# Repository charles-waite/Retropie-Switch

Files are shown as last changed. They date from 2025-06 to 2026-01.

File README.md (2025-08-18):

# Raspberry Switch

A handheld, modular, Raspberry Pi-based game console inspired by the Nintendo Switch.  
Designed for RetroPie gaming, open-source hacking, and custom hardware add-ons—housed in a 3D-printed case with real Switch Joycons and tailored for hardware tinkerers.

---

## Table of Contents

- [Project Overview](#project-overview)
- [Features](#features)
- [Hardware List](#hardware-list)
- [Case & Design Notes](#case--design-notes)
- [Joycon Rail Connector](#joycon-rail-connector)
- [To-Do](#to-do)
- [Setup & Install Instructions](#setup--install-instructions)
- [Development Roadmap](#development-roadmap)
- [License](#license)
- [Acknowledgments](#acknowledgments)

---

## Project Overview

**Raspberry Switch** is a DIY handheld gaming console based on the Raspberry Pi 3A+, with a 7" touchscreen, true Joycon compatibility, built-in audio, battery power, and an open 3D-printed enclosure.  
This project aims to be a “Switch-like” device running RetroPie, with modular Python scripts handling hardware functions like backlight, volume, overlay, battery status, and LED indicators.

All hardware and software designs are eventually intended to be open-sourced for others to build, adapt, and contribute.

---

## Features

- RetroPie-based, runs classic games on a handheld Pi
- 3D-printed clamshell case with access panels
- Real Nintendo Switch Joycon rails for detachable controls
- USB-C charging with PiSugar UPS and battery support
- 7” touchscreen display with adjustable backlight (including auto-brightness)
- Custom volume controls (including hardware mute and OSD overlay)
- Stereo amp and speakers (with mini DAC for high-quality audio)
- Headphone jack with auto-mute detection
- On-screen overlays for status and actions
- Status LEDs for power, charging, and battery
- Expandable via internal USB hub for extra controllers/devices
- Open design—schematics, scripts, and CAD files included

---

## Hardware List

- Raspberry Pi 3A+
- PiSugar 3 Plus (battery/UPS)
- 7” Touchscreen display
- Switch Joycon rails (or donor Joycon charger for rails/connector)
- Joycons
- Tiny stereo speakers
- Mini DAC (generic PCM5102A variant)
- Small hardware buttons (power, volume, etc.)
- USB-C charging input relocated/extended from PiSugar
- Liquid flux

---

## Progress pictures

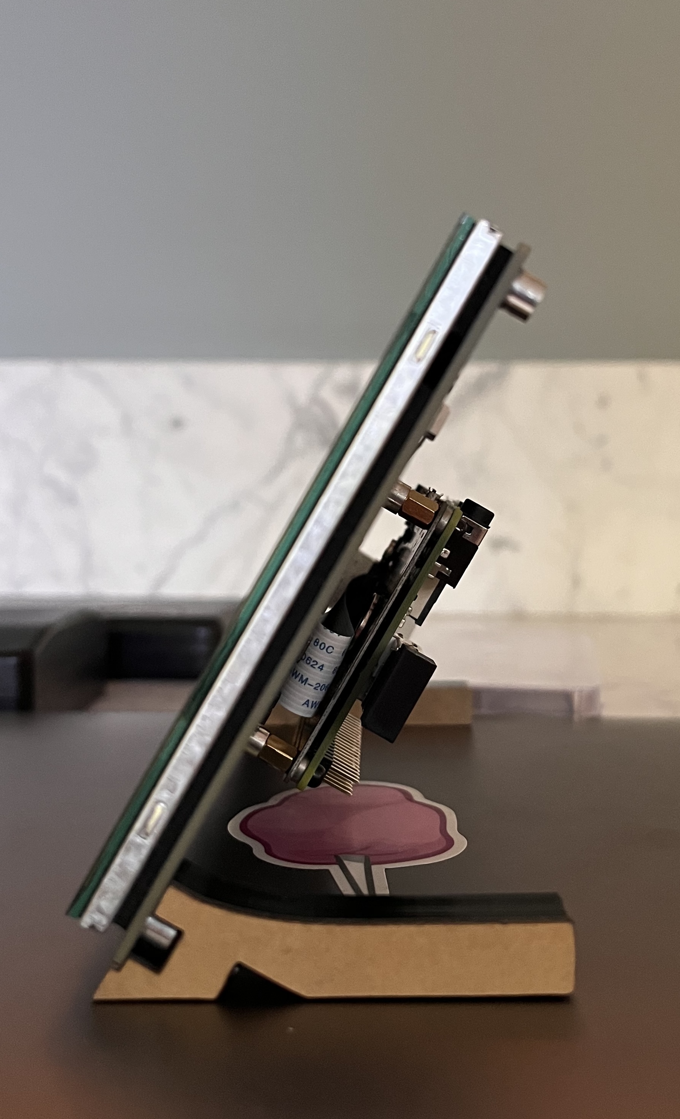
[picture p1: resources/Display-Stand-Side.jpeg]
Display Stand Side

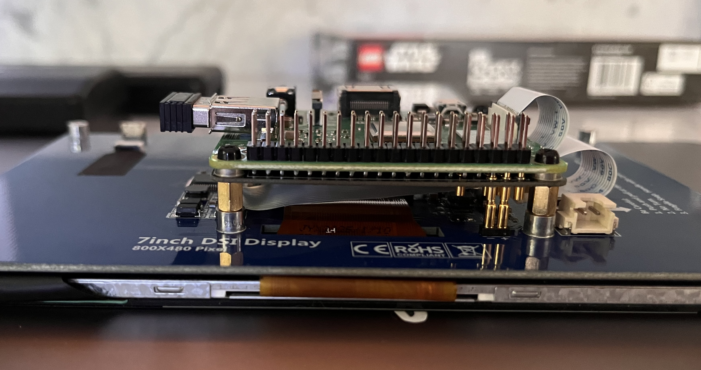
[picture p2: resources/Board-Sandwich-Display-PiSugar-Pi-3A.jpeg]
Board Sandwich


---

## Case & Design Notes

- Custom 3D-printed, clamshell design in two layers (screen bezel, rear case)
- Mounts for all internal components (speakers, amp, DAC, buttons, USB, Joycon rails)
- Foam or adhesive for clean fit to screen
- Mounts directly to LCD panel studs for a robust build

---

## To-Do

- [ ] **Design v1 case** (simple POC, clamshell, access ports)
    - Mounts for speakers, amp, headphone jack, DAC, buttons, USB, Joycon rails, controller board, battery
- [ ] **Integrate buttons** for volume, power, etc.
- [ ] **Upgrade to PiSugar 3 Plus** for power management
- [ ] **Add internal USB hub** (minimum 3 ports: 2 external, 1 internal for Joycons)
- [ ] **Optimize DAC mounting** for durability and space
- [ ] **Setup & test volume/mute buttons**, with auto-mute on headphone insertion
- [ ] **Setup backlight control script**, test with Joycons
- [x] **Create GitHub repo**
- [ ] **Create installer/setup script**
    - [ ] Registers system services at boot
    - [ ] Links scripts and services correctly
    - [ ] Includes update script for pulling changes & restarting services
- [ ] **Refactor scripts** to use Adafruit libraries for reliability
- [ ] **Determine ribbon cable orientation for Joycon rails**
- [x] **Design Joycon Rail cable extender and breakout board variants**
- [ ] **Design custom slider rails using a 4-pin connector to carry VIN/GND + I2C signal**
	- 	Could use a Magnetic "MagSafe" style plug, USB-C plugs, or something like a card edge connector.

---

## Setup & Install Instructions

### 1. Prepare SD Card

- Download and flash the RetroPie IMG to your SD card, or
- Install Raspbian 64-bit Lite (Bookworm) to SD

> **Note for Pi 3/3+:**  
> - Disable WiFi Power Management:  
>   Edit `/etc/rc.local` and add:  
>   ```sh
>   /sbin/iwconfig wlan0 power off
>   exit 0
>   ```
>   Run: `sudo chmod 755 /etc/rc.local`
> - Follow [raspberrypi5-retropie-setup instructions](https://github.com/danielfreer/raspberrypi5-retropie-setup)

### 2. Boot Configuration

- Edit `boot.txt`, comment out `#dtparam=audio=on`
- (Double-check these steps for Bookworm compatibility)

### 3. System Updates

- `sudo apt-get update`
- `sudo apt-get upgrade`
- Boot into RetroPie, run system updates

### 4. Audio & Volume Controls

- Configure virtual sound card for SoftVolume control
- Set up hardware volume/mute buttons and OSD overlay
- Integrate auto-mute on headphone detection (using headphone jack GPIO switch)

### 5. Backlight & Sensor

- Connect and script ambient light sensor to GPIO for auto backlight
- Connect LCD backlight control to GPIO/PWM pin

### 6. Joycon Rails

- Wire rails using Molex ribbon cables per plan above
- Test fit for correct cable orientation and slot routing

### 7. Installer Script (planned)

- Run installer script to set up services and scripts at boot
- Update script for future improvements

---

## Development Roadmap

- Modular Python scripts for backlight, volume, overlay, battery, and status LEDs
- Hardware abstraction to allow swapping components (DAC, screen, battery, etc.)
- Easy-to-follow setup and assembly documentation (including CAD files and images)
- Comprehensive OSD overlay for quick status/config access
- Plug-and-play Joycon integration
- Planned public open-source release when project reaches v1.0

---

## License

*To be added upon public release. Consider using [MIT](https://choosealicense.com/licenses/mit/) or [GPLv3](https://choosealicense.com/licenses/gpl-3.0/) license.*

---

## Acknowledgments

- Inspired by the Nintendo Switch, RetroPie, and countless open-source handheld projects

---

## Contributing

*Contributions, feedback, and hardware test reports are welcome! Please open issues or pull requests once the repo is public.*

---

## Contact

Project lead: charles-waite  
For questions, suggestions, or to get involved, open an issue.

---

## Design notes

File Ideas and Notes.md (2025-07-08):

**Raspberry Switch**

**Ideas:**

**A RetroPie-based Switch clone**

3D Printed Case (custom or using existing design as template)

- Built-in RPi 3A + Battery/UPS + Stereo Amp + Speakers
- Switch Joycon rails wired to charge joycons
- Removable back panel for access to Pi
- Mounts to lcd panel studs
- Gasket/adhesive for clean fit to screen

Ergo-Grips for real Joycons

- Or 3rd Party Ergo Joycon replacements with switch rails
- May need a premade joycon charger to pillage parts from

RetroPie

7” Touchscreen

Relocated Headphone Jack

USB-C charging jack on top or side wired to battery/UPS

Power Button

Volume buttons (or figure out OSD solution)

v2 - External HDMI port (hdmi over usbc?)

**Parts List:**

Pi 3 A+

PiSugar 3 Plus

7” Touchscreen

Switch Side rails -OR- Joycon charger to pillage 

Joycons

Tiny Stereo Speakers

Small buttons for power/volume

USB-C connector

Small gauge wires

Liquid flux

Small gauge solder

**Plan for joycon:**

- Scavenge board and rails from charging joycon
- Solder tiny wires to rail ribbon cable to extend connection to board from far sides
- Should work with *Joycond* out of the box via USB
- Connect to USB bus with wires rather than connector

**Plan for audio**

- BT audio is a non-starter for now
- Use mini DAC 
- Setup SoftVol to control volume to DAC
- Wire speaker amp to rca output pads on DAC
- Use I2C gain controls on amp to turn it all the way down when both volume buttons are pressed (this will functionally work as a mute switch too)
  - Need to figure out button combos and long press for this to work properly.
- Pressing both buttons again restores the gain value back to a specified setting.
- Maybe switch volume controls to be more logarithmic?

**Design a popup menu for custom actions to be run**

- Could be used to manually mute audio or run scripts to make basic config changes.

**Ambient light sensor for backlight**

Automate backlight brightness using a photocell.

- Can use a cheap phototransistor tied to gpio.
- LCD Backlight can be connected to GPIO-PWM pin and controlled with code
- Could find a script that will monitor that pin and change the output accordingly.

**Space for Audio stuff**

- Mount to lid
- DAC uses gpio header
- Amp is wired to DAC and gets power from GPIO

**USB**

Do I even need more than one? 

- Loading roms over USB
- Secondary controllers? 
- Internal hub (adafruit breakout board) with an externally accessible port or two?

**Status LEDs**

(Tested with adafruit 5mm LEDs https://www.adafruit.com/product/4203)

Green = 220 Ω

Blue = 4,700 Ω

Red = 2,200 Ω

This may differ when I try 3mm ones. Or I could do RGB using a software PWM and a 4-pin RGB LED.

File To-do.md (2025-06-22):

To-do:

- [ ] Design v1 Case

  	Just a POC, can be blocky and doesn't need mounting points for hardware, just space for things to fit. I can use this to mark out where components can mount 

  	Clamshell design in 2 layers: screen bezel, rear case, access port for Pi

  	Mounts include: 

  		• Speakers

  		• Amp board

  		• Headphone Jack (should get a mountable version, breadboard one isnt ideal)

  		• DAC (needs to be really secure to handle GPIO insertion and removal)

  		• Buttons w/ rocker switch pieces

  		• USB ports

  		• Joycon Rails

  		• Joycon controller board

  		• Battery	

- [ ] Integrate buttons for volume, power, etc

- [ ] Upgrade to PiSugar 3Plus to get power on/off

- [ ] Integrate a USB hub: 2 data ports external, one internal for Joycons.

  	• Maybe find a USB hub at home and scavenge it?

  	• Minimum 3 ports

- [ ] Install a header shim to double the 2x20 ports for more seamless connection for buttons, audio amp, usb, etc

- [ ] Consider a [short female header](https://www.adafruit.com/product/2243) for the DAC to save space (may not work with the gpio shim, maybe stack them and solder together?)

- [ ] Setup and test Volume mute button code w/ auto-mute on headphone insertion.

  	• Wire up headphone switch to GPIO to trigger automatic mute (Inner pins are open when headphones are inserted, DAC supports this)

- [ ] Setup Backlight control script and test with Joycons.

- [x] Create Github Repo

- [ ] Create installer/setup script

  - [ ] Creates and registers system services and runs them at boot
  - [ ] Links services to correct locations (would be /home/pi/*REPO-NAME*)
  - [ ] installs scripts to correct directories
  - [ ] Create update script that pulls new scripts and restarts systemctl and services

- [ ] Refactor script to use Adafruit python libraries (since ChatGPT keeps fucking up the registers and forgetting functionality)

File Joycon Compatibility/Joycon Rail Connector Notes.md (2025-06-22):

## Tech Specs

#### Rail-side connector:

Pitch: .5mm

Compatible connector: [Molex 5034801000](https://www.digikey.com/en/products/detail/molex/5034801000/2356624)

Compatible cable: Molex [15020 (top-side pads)](https://www.digikey.com/en/products/filter/flat-flex-ribbon-jumpers-cables/457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) or [Molex 15120(opposite side pads)](https://www.digikey.com/en/products/filter/flat-flex-ribbon-jumpers-cables/457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) (length and pad side determined by routing layout and connectors)

#### Mounting plan:

1. Desolder original rail connector from original cable.
2. Solder original rail connector to one side of Molex flat cable.
3. Solder new molex connector to original cable.
4. Run flat cable through case to reach joycon board location.
5. New molex flat cable will plug into new connector on original cable

#### To-Do

Need to determine if same-side or opposite-side cables are needed for each side by doing a test fit with paper.

A slot will need to be designed into the rail mounting surface of the case in order to accomodate the new ribbon cable.

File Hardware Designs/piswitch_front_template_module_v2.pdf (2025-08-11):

| Active 154.89 x 87.50 mm (offset 1.62 L, 2.38 U)
| Module outline 164.89 x 100.00 mm
Left grip, 15.0° outward | | Right grip, 15.0° outward

Rail zone

Rail zone

Bezel mm: L=3.25 R=6.5 T=3.75 B=8.5; Active offset = 1.62 L, 2.38 U Print at 100% for 1:1.

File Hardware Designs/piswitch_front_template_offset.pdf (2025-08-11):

| Screen plate 176.4 x 115.4 mm (+12 mm uniform bezel) | Active area 152.4 x 91.4 mm (offset 1.62 mm L, 2.38 mm U)
Left grip, 15.0° outward | | | Right grip, 15.0° outward

Rail zone

Rail zone

Page: 300 x 160 mm. Print at 100% for 1:1.
Offset from bezel widths (mm): L=3.25 R=6.5 T=3.75 B=8.5

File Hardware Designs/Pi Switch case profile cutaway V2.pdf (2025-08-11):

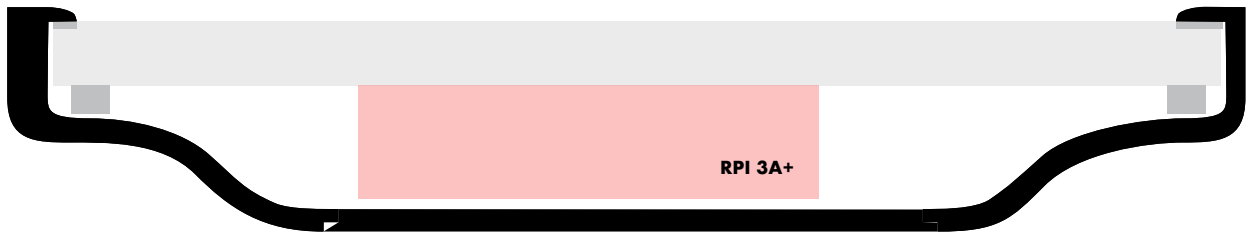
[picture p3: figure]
RPI 3A+

SHORT SIDE CROSS-SECTION

LONG SIDE CROSS-SECTION (FROM BOTTOM)

BEZEL WIDTHS

TOP: | 3.75MM
BOTTOM: | 8.50MM
LEFT: | 3.25MM
RIGHT: | 6.50MM

RPI 3A+

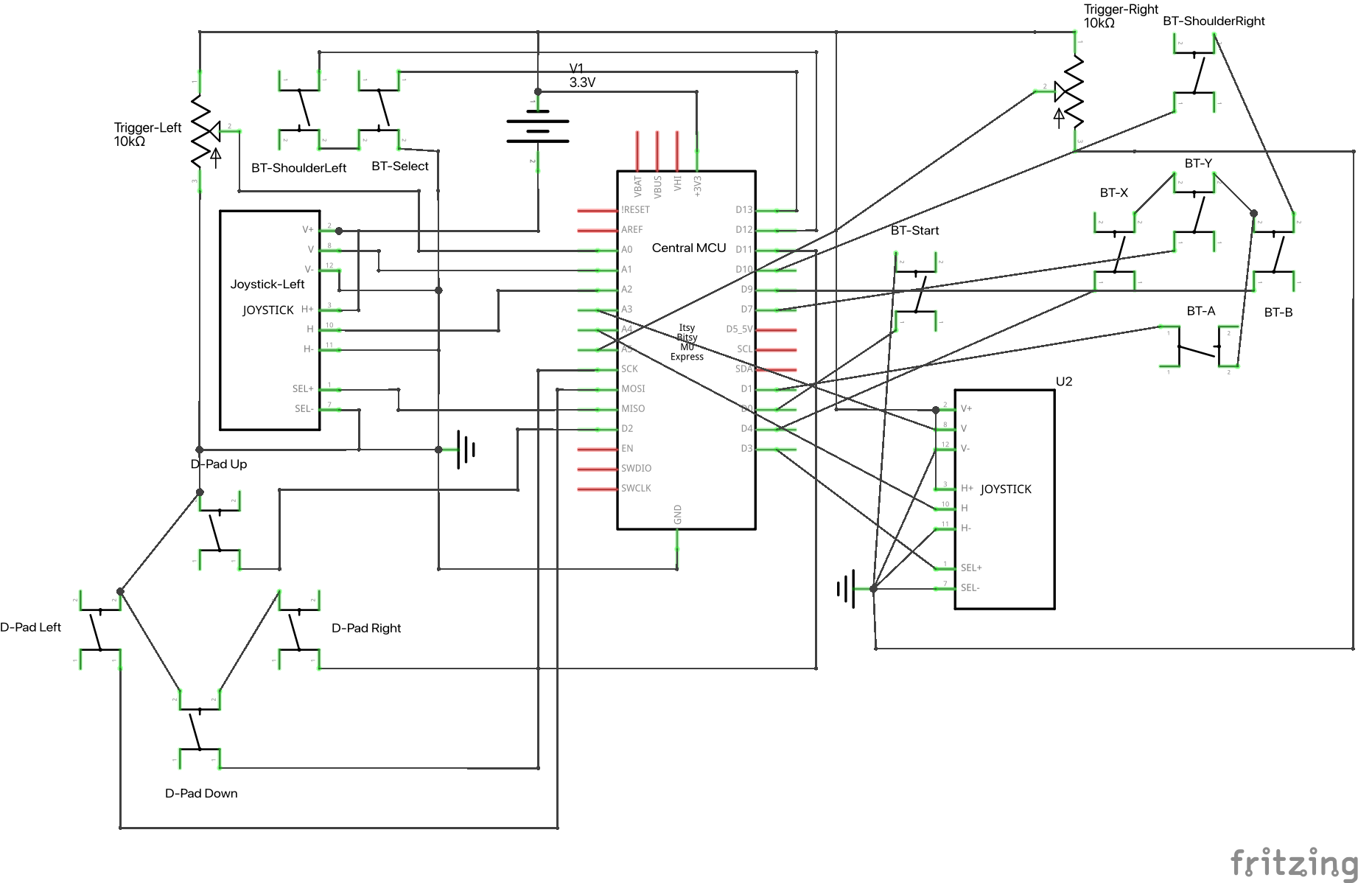
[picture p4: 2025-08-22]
Hardware Designs/Unified controller_schem.png

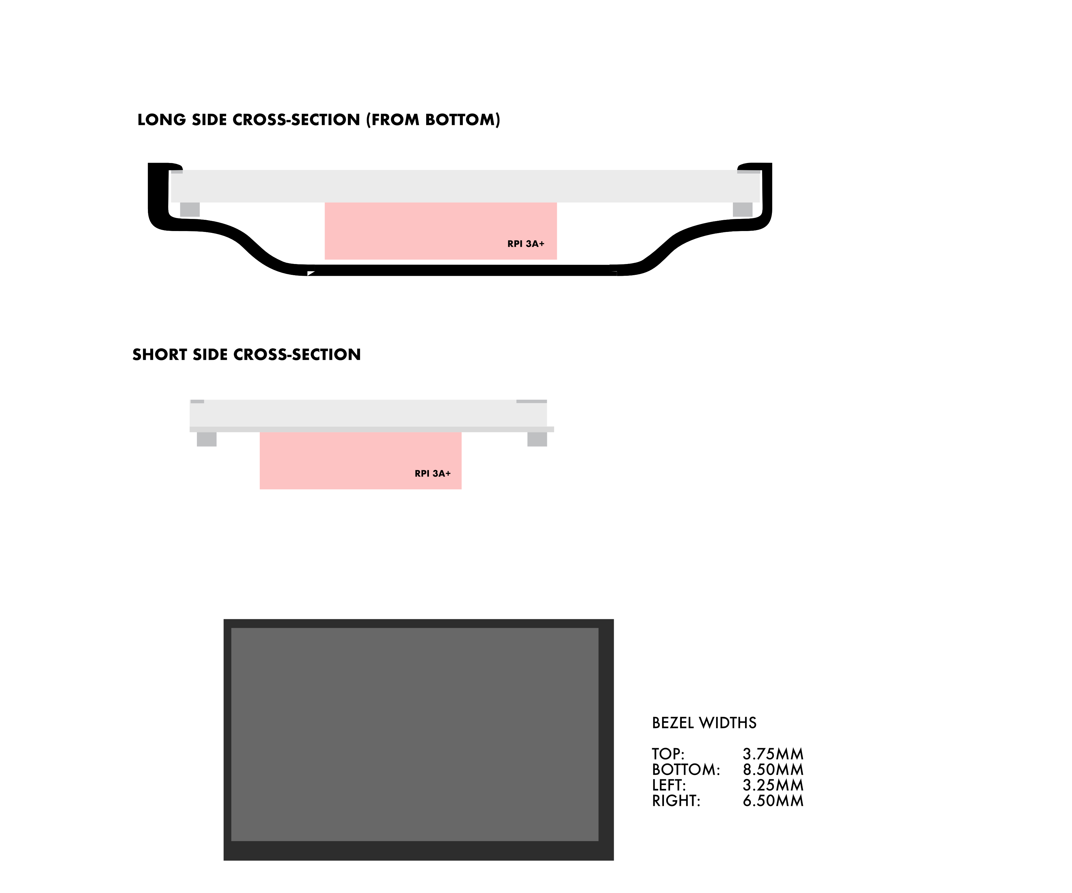
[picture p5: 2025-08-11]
Hardware Designs/Pi Switch case profile cutaway v2.png

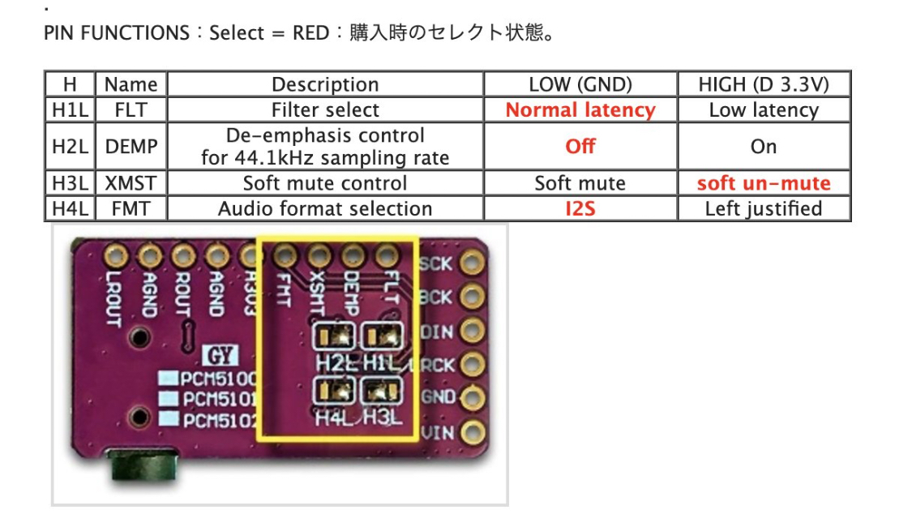
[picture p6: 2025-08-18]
resources/PCM5102A-board-jumper-pinout.jpeg

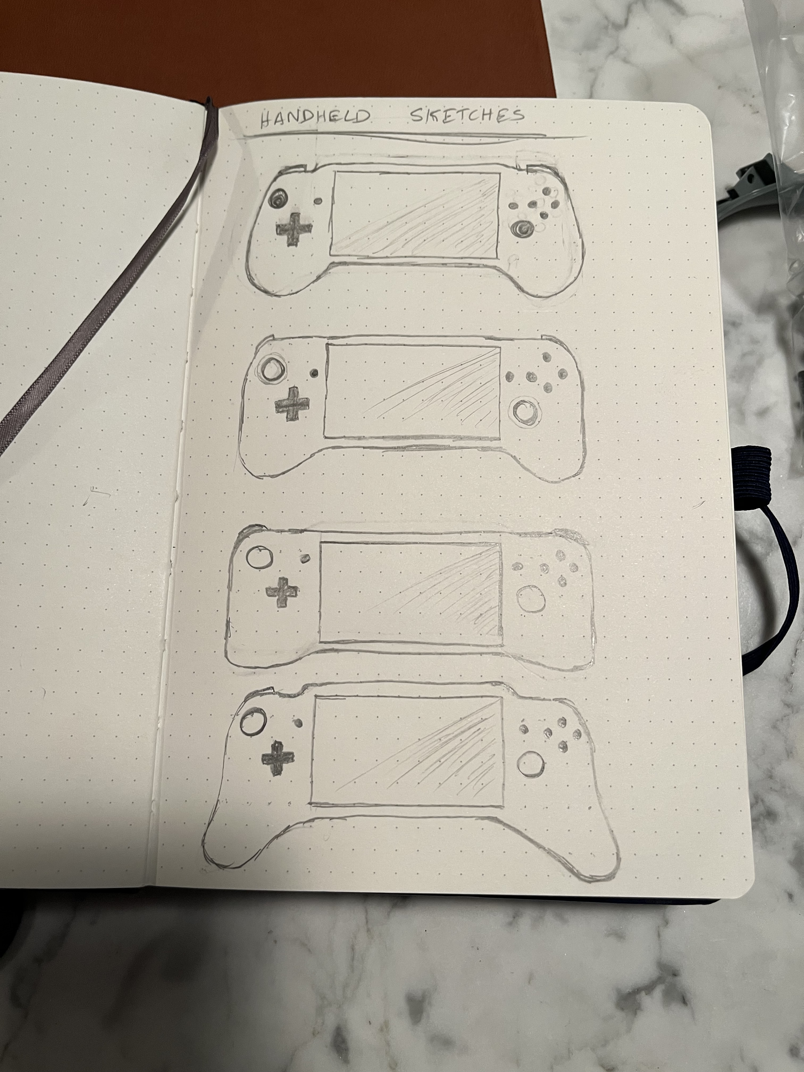
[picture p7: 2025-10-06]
resources/PiSwitch case Sketches.jpeg

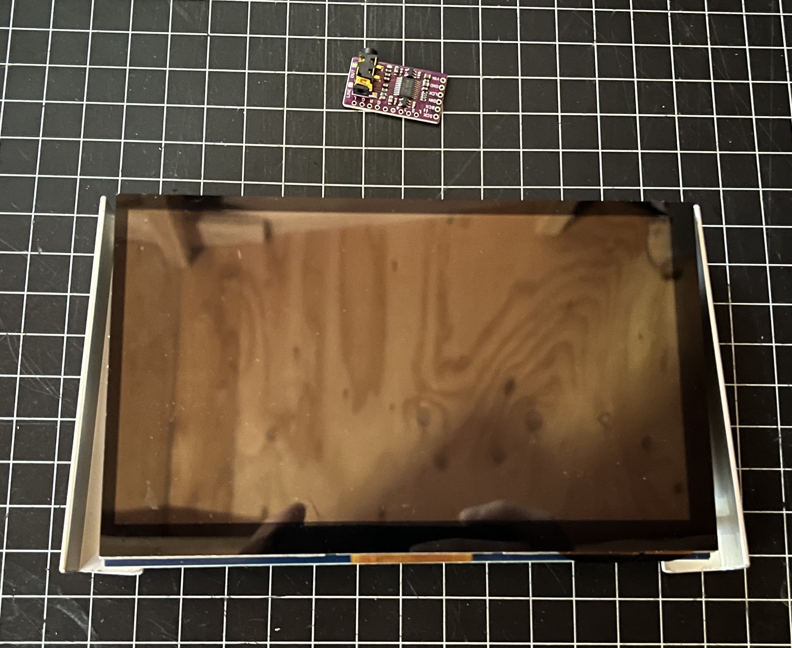
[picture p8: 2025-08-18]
resources/Prototype-Front-view.jpeg

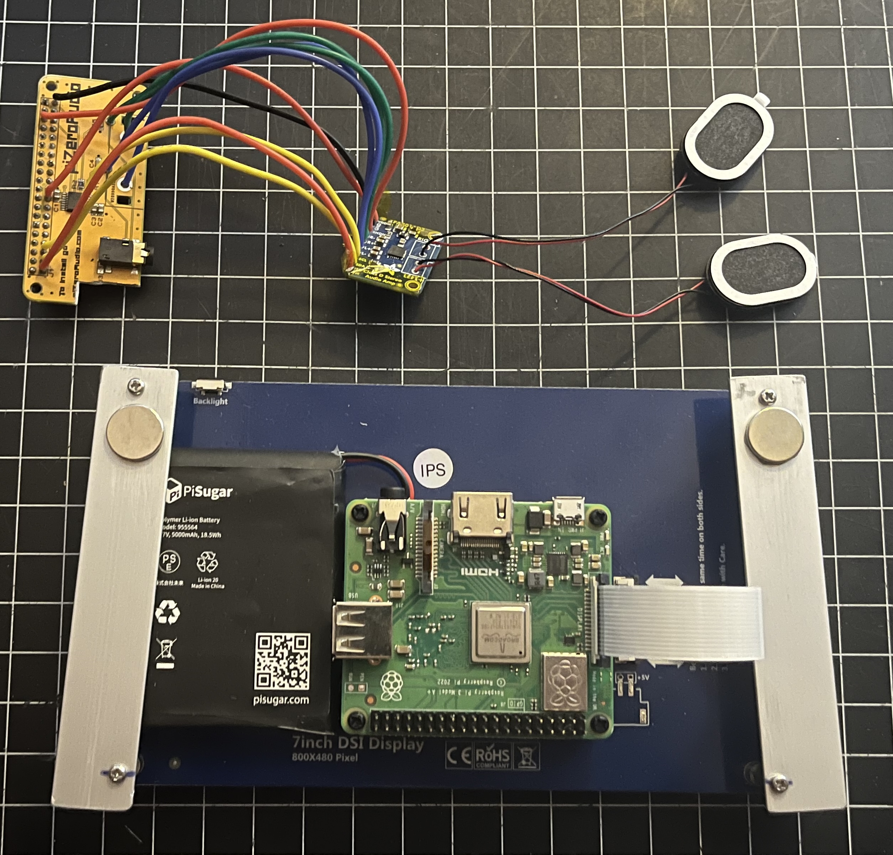
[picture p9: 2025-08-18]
resources/Prototype-Back-view.jpeg

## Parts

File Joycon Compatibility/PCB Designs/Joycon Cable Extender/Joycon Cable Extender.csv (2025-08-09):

Reference | Qty | Value | DNP | Exclude from BOM | Exclude from Board | Footprint | Datasheet
J3,J4 | 2 | Molex_5035661102 |  |  |  | CON_5035661102_MOL | https://www.molex.com/en-us/products/part-detail-pdf/5035661102?display=pdf

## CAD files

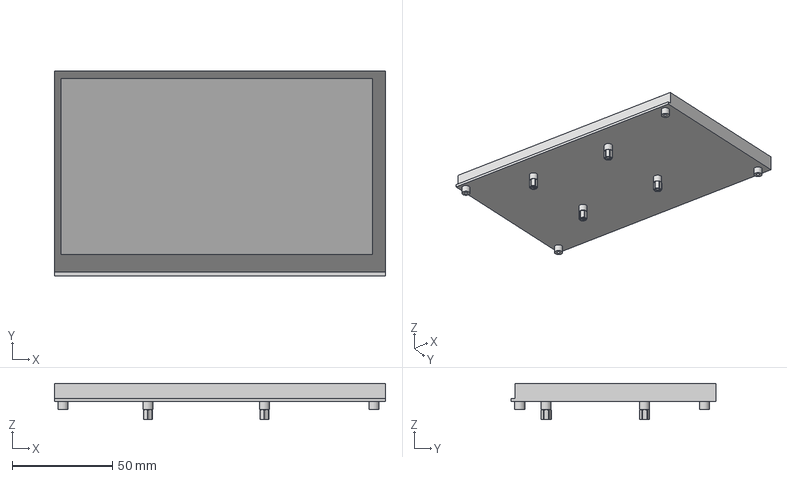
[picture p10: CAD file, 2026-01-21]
Hardware Designs/Models/7-inch Screen.step
164.8 x 102.0 x 18.1 mm
93655A090_Male-Female Threaded Hex Standoff x 4

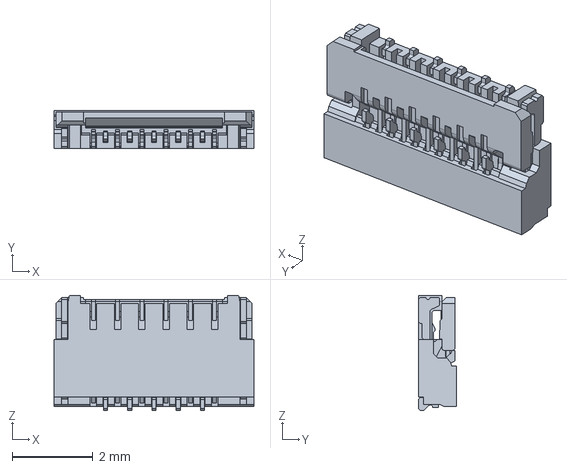
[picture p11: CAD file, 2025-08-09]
Joycon Compatibility/PCB Designs/Joycon Cable Breakout/166394007-659-5035661102/5035661102.stp
4.95 x 0.95 x 2.85 mm

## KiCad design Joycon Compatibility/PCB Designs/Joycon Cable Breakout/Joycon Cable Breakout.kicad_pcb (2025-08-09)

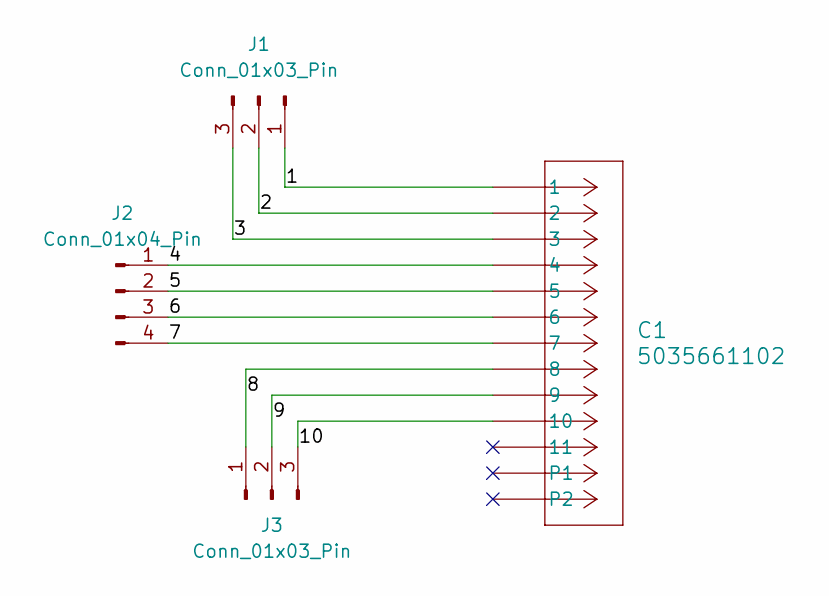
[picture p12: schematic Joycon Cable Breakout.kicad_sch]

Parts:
C1: 5035661102; CON_5035661102_MOL
J1, J3: Conn_01x03_Pin; 3-pad-sm
J2: Conn_01x04_Pin; 4-pad-sm-vert

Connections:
/1: C1.1, J1.1
/2: C1.2, J1.2
/3: C1.3, J1.3
/4: C1.4, J2.1
/5: C1.5, J2.2
/6: C1.6, J2.3
/7: C1.7, J2.4
/8: C1.8, J3.1
/9: C1.9, J3.2
/10: C1.10, J3.3

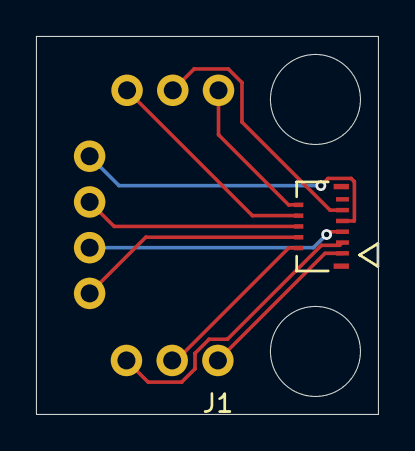
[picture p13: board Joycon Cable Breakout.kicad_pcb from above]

Board: 2 copper layers, 19.0 x 21.0 mm, 4 parts (0 on the bottom side), 10 nets.

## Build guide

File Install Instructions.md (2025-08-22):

## RetroPie Config Steps

#### 1. Prepare SD Card
 1. Download Raspberry Pi Imager.
 2. Open Raspberry Pi Imager and select the Pi device you're using.
 3. Select the RetroPie image under "Emulation and Game OS" -> RetroPie -> Select the image for your Pi model.
 4. Select the SD card you're installing RetroPie onto.
 5. Click Edit Settings to configure Wifi settings, hostname (optional), select time zone and keyboard localization, and enable SSH (highly recommended) in the Edit Settings screen. 
 6. Save settings
 7. Then click the Yes button to install RetroPie.
#### 2. Modify boot.txt  
1. Once the install is complete, mount the SD card (if your OS hasn't already)
2. Run: `sudo nano /boot/config.txt` and make the following changes:
3. Disable internal audio: `#dtparam=audio=on`
4. Add this to the end of the file: `dtoverlay=hifiberry-dac`
5. –––ADD MORE HERE–––– 
#### 3. Insert SD into Pi and boot into Retropie 
> [!IMPORTANT] 
>
> **For Pi 3 and 3+ variants:**   
> If Wifi Power management is not disabled, ssh connections will constantly fail, bluetooth will be very flaky and wifi connectivity will be very spotty. Implementing this small fix likely will increase power consumption but is necessary in my case for functioning wifi.
>  
** Disable Wifi Power Management:  **
> 1. SSH into pi once booted. use command: `sudo ssh pi@you.local.ip.address`. default password is `raspberry`
> 
> 2. Create rc.local file in nano using: `sudo nano /etc/rc.local`  
>
> 3. In nano, add this code:
>>```sh
>>    #!/bin/sh -e 
>>    /sbin/iwconfig wlan0 power off 
>>    exit 0
>>    ```
>    
> 4. Save file and exit nano.
>
> 5. Run this command to give script executable permissions:  `sudo chmod 755 /etc/rc.local`
> 6. This script should persist across boots and run automatically to restore functioning wifi.
> 7. Reboot pi with `sudo reboot`.
#### 4. Upgrade Retropie components.
This can be done in the GUI with an attached controller or keyboard or via SSH.
**GUI:**
1. Once RetroPie is booted, scroll to the settings.
2. Choose the RetroPie Setup option.
3. Select "Update" from the menu.
4. This will take a while depending on the Pi model, but it will scan through and update all installed components.

**SSH:**
1. SSH into your pi: `sudo ssh pi@you.local.ip.address`
2. Run `sudo ~/RetroPie-Setup/retropie_setup.sh`
#### 5. Backlight & Ambient light sensor
- Basic command to set brightness: `echo [integer between 0-255] | sudo tee /sys/class/backlight/rpi_backlight/brightness`
- Add integration with planned overlay for volume battery and change to a percentage rather than an integer for UI simplicity
- *Ambient Light sensor is low priority and for future iteration (if at all).*
#### 6. Configure virtual sound card for SoftVolume control.
If your DAC doesn't support ALSA Mixer functions (many don't), you need to setup a system level software control so that you can control system volume.
Raspi Audio has a script that will set this up automatically. You must complete these steps in this order, including the reboots.
1. Run this from SSH: `sudo wget -O - script.raspiaudio.com | bash`
2. Reboot.
3. Test audio with `sudo speaker-test -l5 -c2 -t wav`. You should hear audio output via headphone jack or connected speakers.
4. Reboot.
5. Volume should now be controllable via `alsamixer`.
Confirm this is necessary and if so, that it still works with PCM5102A DAC. Can copy contents of `/etc/asound.conf` file for manually setup code.

#### 6. Setup volume buttons for Master volume and Mute for TPA2016 amp

#### 7. Copy ROMs to SD-Card.

#### 8. (Optional) Set boot splashscreen for correct display resolution
#### 9. (Optional) Install SkyScraper metadata scraper.

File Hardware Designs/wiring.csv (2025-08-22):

Side | Control | Pad Role | ItsyBitsy Pin
Both | Common Ground Bus | GND | GND
Both | 3.3V Rail (sticks + triggers) | VCC | 3V
Left | D‑Pad Up | Signal | D2
Left | D‑Pad Down | Signal | SCK
Left | D‑Pad Left | Signal | MOSI
Left | D‑Pad Right | Signal | D11
Left | BT‑ShoulderLeft (LB) | Signal | D12
Left | BT‑Select | Signal | D13
Left | Joystick‑Left X | Wiper | A2
Left | Joystick‑Left X | VCC | 3V
Left | Joystick‑Left X | GND | GND
Left | Joystick‑Left Y | Wiper | A1
Left | Joystick‑Left Y | VCC | 3V
Left | Joystick‑Left Y | GND | GND
Left | L3 (Stick Click Left) | Signal | MISO
Left | Trigger‑Left (LT) | Wiper | A0
Left | Trigger‑Left (LT) | VCC | 3V
Left | Trigger‑Left (LT) | GND | GND
Right | BT‑A | Signal | D1
Right | BT‑B | Signal | D9
Right | BT‑X | Signal | D4
Right | BT‑Y | Signal | D7
Right | BT‑ShoulderRight (RB) | Signal | D10
Right | BT‑Start | Signal | D0
Right | Joystick‑Right X | Wiper | A5
Right | Joystick‑Right X | VCC | 3V
Right | Joystick‑Right X | GND | GND
Right | Joystick‑Right Y | Wiper | A4
Right | Joystick‑Right Y | VCC | 3V
Right | Joystick‑Right Y | GND | GND
Right | R3 (Stick Click Right) | Signal | D3
Right | Trigger‑Right (RT) | Wiper | A3
Right | Trigger‑Right (RT) | VCC | 3V
Right | Trigger‑Right (RT) | GND | GND

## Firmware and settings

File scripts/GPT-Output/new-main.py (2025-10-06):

# main.py — Custom HID gamepad (ItsyBitsy M0 Express)
# Requires:
#   - boot.py              (defines 9-byte HID: 16 buttons, hat, 6 axes)
#   - button-pinout.json   (pin mapping)
#   - config.json          (invert, deadzone, smoothing, trigger calibration)
#
# Design:
#  - Buttons & D-pad: event-driven via keypad.Keys (less USB chatter, built-in debounce)
#  - Sticks + triggers: polled analog (continuous), then tuned by config and packed into HID
#  - Axes are sent as 8-bit (0..255) values to match the 1-byte-per-axis HID descriptor

import time
import json
import board
import analogio
import usb_hid
import keypad

PINS_FILE = "button-pinout.json"
CONFIG_FILE = "config.json"

# ---------- JSON loader (supports // comments) ----------
def load_json(path, default=None):
    try:
        with open(path, "r") as f:
            lines = []
            for line in f:
                if line.lstrip().startswith("//"):
                    continue
                lines.append(line)
            return json.loads("".join(lines))
    except Exception:
        return default


# ---------- Pin resolver ("MOSI (D4)" -> D4, etc.) ----------
def resolve_pin(label: str):
    label = (label or "").strip()
    # Allow forms like "MOSI (D4)" -> prefer inner D4 if present
    if "(" in label and ")" in label:
        inner = label[label.find("(") + 1 : label.find(")")]
        if inner in dir(board):
            return getattr(board, inner)
    # Direct names like "D9", "A0"
    if label in dir(board):
        return getattr(board, label)
    raise ValueError("Unknown pin label: " + label)


# ---------- Load mapping & config ----------
mapping = load_json(PINS_FILE)
assert mapping is not None, f"{PINS_FILE} not found or invalid"

config = load_json(CONFIG_FILE, default={})
INVERT = config.get("invert", {})  # e.g. {"LY": true, "RY": true}
DEADZONE = config.get("deadzone", {})  # raw 0..255 delta around 128
SMOOTH = config.get("smoothing", {})  # 0.0..1.0 per axis
TRIG = config.get("triggers", {})  # {LT_min, LT_max, RT_min, RT_max}

# Deterministic host button order (typical Xbox-like expectation)
BUTTON_ORDER = ["A", "B", "X", "Y", "LB", "RB", "Start", "Select", "L3", "R3"]
button_names = [nm for nm in BUTTON_ORDER if nm in mapping["buttons"]]
button_pins = [resolve_pin(mapping["buttons"][nm]) for nm in button_names]

# D-pad (Up, Down, Left, Right) — each is its own input, mapped to an 8-way hat
dpad_pins = [
    resolve_pin(mapping["dpad"]["Up"]),
    resolve_pin(mapping["dpad"]["Down"]),
    resolve_pin(mapping["dpad"]["Left"]),
    resolve_pin(mapping["dpad"]["Right"]),
]

# ---------- Hardware setup ----------
buttons = keypad.Keys(button_pins, value_when_pressed=False, pull=True)
dpad = keypad.Keys(dpad_pins, value_when_pressed=False, pull=True)

axes_pins = {ax: resolve_pin(mapping["axes"][ax]) for ax in mapping["axes"]}
lx = analogio.AnalogIn(axes_pins["LX"])
ly = analogio.AnalogIn(axes_pins["LY"])
rx = analogio.AnalogIn(axes_pins["RX"])
ry = analogio.AnalogIn(axes_pins["RY"])
lt = analogio.AnalogIn(axes_pins["LT"])  # keep triggers fully analog
rt = analogio.AnalogIn(axes_pins["RT"])

# Find our custom HID gamepad (Usage Page 0x01, Usage 0x05), as defined in boot.py
gamepad = None
for d in usb_hid.devices:
    if d.usage_page == 0x01 and d.usage == 0x05:
        gamepad = d
        break
assert gamepad, "No custom HID gamepad found (check boot.py)"

# ---------- Helpers ----------
AXIS_STATE = {}  # stores last smoothed value per axis (for low-pass)
CENTER = 128  # center for 8-bit axes


def read_axis(adc, name):
    # NOTE: AnalogIn.value is always 16-bit (0..65535) regardless of MCU ADC resolution.
    # Shift >> 8 to scale into 8-bit (0..255) because the HID descriptor is 1 byte per axis.
    raw = adc.value >> 8

    # Invert if requested
    if INVERT.get(name, False):
        raw = 255 - raw

    # Trigger calibration (map [min..max] -> [0..255])
    if name in ("LT", "RT"):
        minv = TRIG.get(f"{name}_min", 0)
        maxv = TRIG.get(f"{name}_max", 255)
        span = max(1, (maxv - minv))
        raw = int((raw - minv) * 255 / span)
        if raw < 0:
            raw = 0
        if raw > 255:
            raw = 255

    # Deadzone (sticks typically): clamp to center if within threshold
    dz = DEADZONE.get(name, None)
    if dz is not None and abs(raw - CENTER) < dz:
        raw = CENTER

    # Low-pass smoothing (simple EMA): val = (1-a)*prev + a*raw
    a = SMOOTH.get(name, 0.0)
    prev = AXIS_STATE.get(name, raw)
    val = int((1.0 - a) * prev + a * raw)
    AXIS_STATE[name] = val
    return val


def compute_hat(u, d, l, r):
    # 0=U,1=UR,2=R,3=DR,4=D,5=DL,6=L,7=UL,8=center
    if u and not d and not l and not r:
        return 0
    if u and not d and not l and r:
        return 1
    if not u and not d and not l and r:
        return 2
    if not u and d and not l and r:
        return 3
    if not u and d and not l and not r:
        return 4
    if not u and d and l and not r:
        return 5
    if not u and not d and l and not r:
        return 6
    if u and not d and l and not r:
        return 7
    return 8


# ---------- State & report ----------
button_bits = 0
hat = 8  # neutral


def send_report():
    # Pack 9-byte report to match boot.py descriptor:
    # [0,1]=buttons (16 bits), [2]=hat (low nibble), [3..8]=LX,LY,RX,RY,LT,RT
    report = bytearray(9)
    report[0] = button_bits & 0xFF
    report[1] = (button_bits >> 8) & 0xFF
    report[2] = hat & 0x0F
    report[3] = read_axis(lx, "LX")
    report[4] = read_axis(ly, "LY")
    report[5] = read_axis(rx, "RX")
    report[6] = read_axis(ry, "RY")
    report[7] = read_axis(lt, "LT")
    report[8] = read_axis(rt, "RT")
    gamepad.send_report(report)


# ---------- Main loop ----------
while True:
    # Buttons (event-driven): update bitfield only on changes
    ev = buttons.events.get()
    while ev:
        mask = 1 << ev.key_number  # index matches BUTTON_ORDER
        if ev.pressed:
            button_bits |= mask
        else:
            button_bits &= ~mask
        send_report()
        ev = buttons.events.get()

    # D-pad: sample continuously to allow diagonals
    up = not dpad.keys[0].value
    down = not dpad.keys[1].value
    left = not dpad.keys[2].value
    right = not dpad.keys[3].value
    new_hat = compute_hat(up, down, left, right)
    if new_hat != hat:
        hat = new_hat
        send_report()

    # Axes (continuous): always poll to keep motion/pressure smooth
    send_report()
    time.sleep(0.01)  # ~100 Hz overall; adjust if you want faster/slower

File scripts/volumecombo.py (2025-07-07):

import time
import subprocess
import sys
import select
import RPi.GPIO as GPIO
from smbus2 import SMBus

# ========== CONFIGURATION ==========
BUTTON_UP = 17         # GPIO for Volume Up button
BUTTON_DOWN = 27       # GPIO for Volume Down button
SHDN_GPIO = 16         # TEMP: GPIO for TPA2016 SHDN pin (set back to 22 later)
JACK_SWITCH_GPIO = 23  # GPIO for headphone jack detect switch
DEBOUNCE_TIME = 0.05   # 50ms polling debounce

# TPA2016 REGISTER MAP (Corrected)
GAIN_REGISTER = 0x05        # Fixed gain setting
CONFIG_REGISTER = 0x01      # Software shutdown
COMPRESS_REGISTER = 0x07    # Max gain (7:4), Compression (1:0)

SOFTWARE_SHUTDOWN_BIT = 1 << 5  # Bit 5 in register 0x01

# Compression settings
COMPRESSION_1TO1 = 0x00  # bits 1:0 = 00
COMPRESSION_4TO1 = 0x02  # bits 1:0 = 10

# Default (reset) value of COMPRESS_REGISTER: 0xC0 (max gain 30dB, 1:1)
DEFAULT_MAXGAIN_BITS = 0b1100  # bits 7:4

# Other settings
I2C_BUS = 1
TPA2016_I2C_ADDR = 0x58
FIXED_GAIN_DB = 0  # Set your preferred default gain here (-28 to +30 dB)

# ========== GLOBALS ==========
current_gain_db = FIXED_GAIN_DB
compression_setting = COMPRESSION_1TO1  # Start at 1:1

# ========== TPA2016 CONTROL ==========
def db_to_regval(db):
    db = max(-28, min(30, db))
    return int(db + 28)

def set_fixed_gain_db(db):
    global current_gain_db
    db = max(-28, min(30, db))
    current_gain_db = db
    with SMBus(I2C_BUS) as bus:
        gain_value = db_to_regval(db)
        bus.write_byte_data(TPA2016_I2C_ADDR, GAIN_REGISTER, gain_value)
        time.sleep(0.05)  # short pause
        readback = bus.read_byte_data(TPA2016_I2C_ADDR, GAIN_REGISTER)
    print(f"Set gain to {db} dB (wrote 0x{gain_value:02X}), read back 0x{readback:02X}")
    if readback != gain_value:
        print("WARNING: Register readback does not match written value!")

def set_compression_ratio(new_ratio_value):
    global compression_setting
    with SMBus(I2C_BUS) as bus:
        val = bus.read_byte_data(TPA2016_I2C_ADDR, COMPRESS_REGISTER)
        val_new = (val & 0xFC) | (new_ratio_value & 0x03)
        bus.write_byte_data(TPA2016_I2C_ADDR, COMPRESS_REGISTER, val_new)
        time.sleep(0.05)
        readback = bus.read_byte_data(TPA2016_I2C_ADDR, COMPRESS_REGISTER)
    compression_setting = new_ratio_value
    ratio_map = {0: "1:1", 1: "2:1", 2: "4:1", 3: "8:1"}
    print(f"Set compression to {ratio_map.get(new_ratio_value, '?')} (wrote 0x{val_new:02X}), read back 0x{readback:02X}")

def toggle_compression():
    # 0 = 1:1, 2 = 4:1
    set_compression_ratio(2 if compression_setting == 0 else 0)

def get_current_compression_label():
    ratio_map = {0: "1:1", 1: "2:1", 2: "4:1", 3: "8:1"}
    return ratio_map.get(compression_setting, "?")

def disable_agc_and_set_gain():
    with SMBus(I2C_BUS) as bus:
        gain_value = db_to_regval(current_gain_db)
        bus.write_byte_data(TPA2016_I2C_ADDR, GAIN_REGISTER, gain_value)
        # Don't overwrite register 0x07, just re-set compression bits
        val = bus.read_byte_data(TPA2016_I2C_ADDR, COMPRESS_REGISTER)
        val = (val & 0xFC) | (compression_setting & 0x03)
        bus.write_byte_data(TPA2016_I2C_ADDR, COMPRESS_REGISTER, val)
        print(f"Fixed gain set to {current_gain_db} dB (reg value {gain_value})")
        print(f"Compression ratio re-applied: {get_current_compression_label()}, reg 0x07 = 0x{val:02X}")

# ========== HARDWARE MUTE (SHDN) ==========
def mute_amp():
    GPIO.output(SHDN_GPIO, GPIO.LOW)
    print("Hardware SHDN: LOW (muted/shutdown)")

def unmute_amp():
    GPIO.output(SHDN_GPIO, GPIO.HIGH)
    time.sleep(0.05)  # Give the amp a moment to power up
    disable_agc_and_set_gain()  # Restore settings after power up
    print("Hardware SHDN: HIGH (unmuted)")

# ========== SOFTWARE MUTE (SWS, REG 0x01, BIT 5) ==========
def sws_software_mute():
    with SMBus(I2C_BUS) as bus:
        reg = bus.read_byte_data(TPA2016_I2C_ADDR, CONFIG_REGISTER)
        reg |= SOFTWARE_SHUTDOWN_BIT
        bus.write_byte_data(TPA2016_I2C_ADDR, CONFIG_REGISTER, reg)
        print("SWS Software Shutdown: ON (muted)")

def sws_software_unmute():
    with SMBus(I2C_BUS) as bus:
        reg = bus.read_byte_data(TPA2016_I2C_ADDR, CONFIG_REGISTER)
        reg &= ~SOFTWARE_SHUTDOWN_BIT
        bus.write_byte_data(TPA2016_I2C_ADDR, CONFIG_REGISTER, reg)
        print("SWS Software Shutdown: OFF (unmuted)")
    disable_agc_and_set_gain()  # Re-assert settings just in case

# ========== ALSA VOLUME ==========
def get_current_volume():
    try:
        import re
        result = subprocess.check_output(["amixer", "get", "Master"], encoding="utf-8")
        matches = re.findall(r"\[(\d+)%\]", result)
        if matches:
            return matches[-1] + "%"
    except Exception as e:
        return "Unknown"
    return "Unknown"

def volume_up():
    try:
        subprocess.run(['/usr/bin/amixer', '-q', '-c', '0', 'sset', 'Master', '5+', 'unmute'])
        vol = get_current_volume()
        print(f"Volume UP, now at {vol}")
    except Exception as e:
        print(f"Volume UP error: {e}")

def volume_down():
    try:
        subprocess.run(['/usr/bin/amixer', '-q', '-c', '0', 'sset', 'Master', '5-', 'unmute'])
        vol = get_current_volume()
        print(f"Volume DOWN, now at {vol}")
    except Exception as e:
        print(f"Volume DOWN error: {e}")

# ========== BUTTON STATE ==========
def both_buttons_pressed(up, down):
    return up == 0 and down == 0

def key_pressed():
    return select.select([sys.stdin], [], [], 0) == ([sys.stdin], [], [])
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

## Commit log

2025-06-22 Initial Commit
    Lots of stuff a WIP, but volume controls mostly tested and functional. Backlight should be functional but untested and needs joycon button mappings.
2025-07-07 Latest Updates
    [Fritzing Test.fzz]
2025-07-08 Update Ideas and Notes.md
    Added 5mm LED resistor values for equalized percieved brightness.
2025-08-09 Joycon Cable boards and case updates
    Lots of updates. Kicad projects for joycon rail cable extender and breakout. Updated case model with first attempt at making a proper case.
    [5035661102.stp, Fritzing Test.fzz, Joycon Cable Breakout.kicad_pcb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]
2025-08-11 Added Case Design SVG
2025-08-11 Further organization
    [5035661102.stp, Fritzing Test.fzz, Joycon Cable Breakout.kicad_pcb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]
2025-08-15 Organization and Fritzing updates
    [Fritzing Test.fzz, PiSwitch Main Components.fzz, Unified controller.fzz]
2025-08-22 Updated Readme, Install instructions, and Gitignore
    [Unified controller wiring table.csv, Unified controller.fzz]
2025-08-22 Sample MCU scripts added. Haven't tested.
    [wiring.csv]
2025-08-28 Create new-main.py
    Revised main.py with event button triggers, smoothing, and clearer documentation.
2026-01-21 Add 7-inch screen STEP model
    Added a new 7-inch Screen STEP file to the hardware models directory for use in mechanical and enclosure design.
    [7-inch Screen.step]
